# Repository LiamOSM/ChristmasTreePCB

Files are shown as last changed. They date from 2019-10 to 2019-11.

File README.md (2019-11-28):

# Christmas Tree PCB
**A PCB Christmas Tree Ornament that glows and plays music!**

This is a thing I designed for McMaster University's IEEE Student Branch. An ATtiny85 microcontroller runs the program I created, which displays several light patterns. Pressing the "Light" button cycles through these patterns. The "Music" button starts a simple version of Jingle Bells, which loops forever until either of the buttons is pressed.

After cycling through all the light modes by pressing the "Light" button, there is an "off" mode. In this mode, the microcontroller is in a deep sleep and the entire circuit draws only 0.2 microamperes. With a standard 200mAh coin cell, the circuit will last over a hundred years in this sleep mode!

The "Light" button actually does a hard-reset to the microcontroller, which is how it's able to exit the sleep mode. Therefore, to make the button able to cycle through modes, the current state is stored in EEPROM. When the microcontroller resets, the state is read from EEPROM, incremented by one, and stored back to EEPROM. If the current state is zero, the microcontroller enters the deep sleep mode. Otherwise, it enters the corresponding light pattern mode.

oops PCB Layout
oops PCB Layout

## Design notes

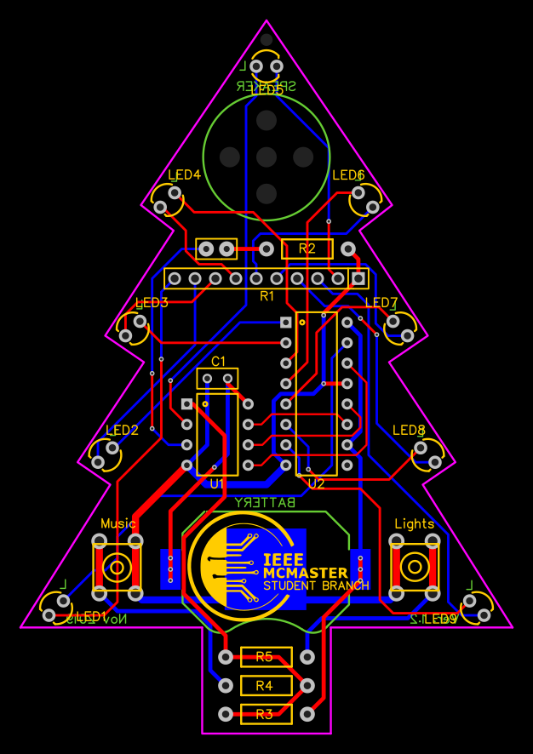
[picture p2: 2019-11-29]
PCB & Circuit Stuff/PCB Layout.png

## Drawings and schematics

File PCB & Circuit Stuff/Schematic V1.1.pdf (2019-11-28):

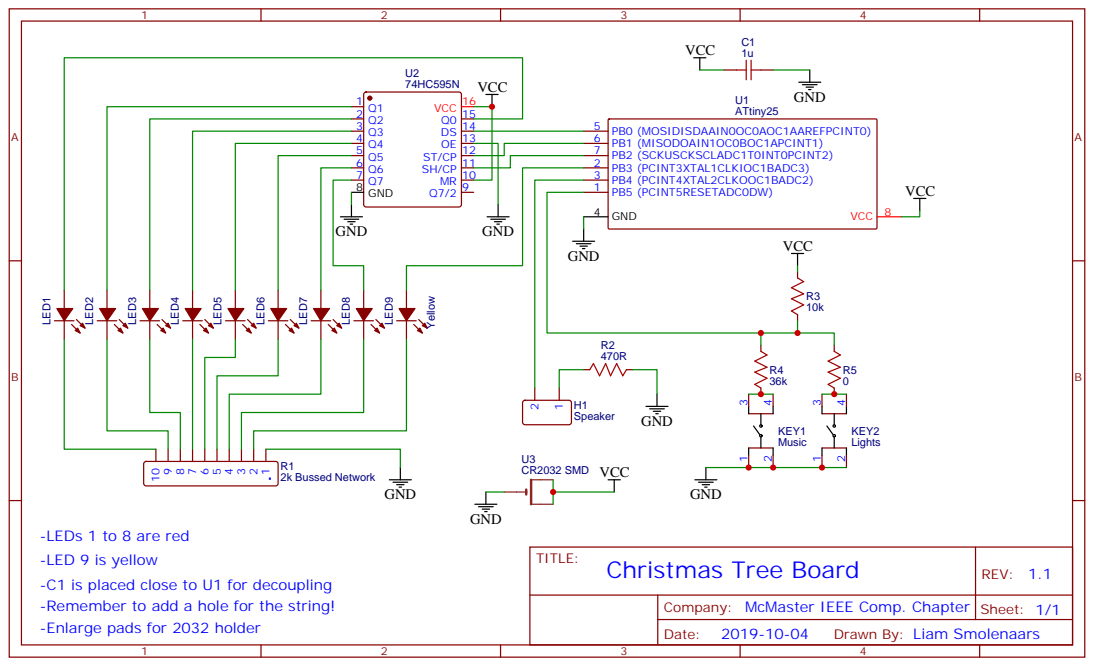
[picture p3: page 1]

MR 10 SH/CP 11 ST/CP 12 OE 13 DS 14 Q0 15 VCC 16

-LEDs 1 to 8 are red
-LED 9 is yellow
-C1 is placed close to U1 for decoupling
-Remember to add a hole for the string!
-Enlarge pads for 2032 holder

Company: McMaster IEEE Comp. Chapter

Drawn By: Liam Smolenaars

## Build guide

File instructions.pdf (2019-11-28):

### Parts List

Quantity | Label | Part Description | Image
1 | R1 | Resistor Network
1 | U1 | ATtiny85 Microcontroller
1 | U1 | 8 Pin Socket
8 | LED1-4, LED6-9 | Red LEDs
1 | LED5 | Yellow LED
1 | C1 | Ceramic Capacitor
2 | Music, Lights | Pushbuttons
1 | Speaker | Speaker
1 | U2 | Shift Register
1 | U2 | 16 Pin Socket
1 | Battery | Battery Holder
1 | Battery | Battery
1 | R3 | 10k Resistor (brown, black, orange)

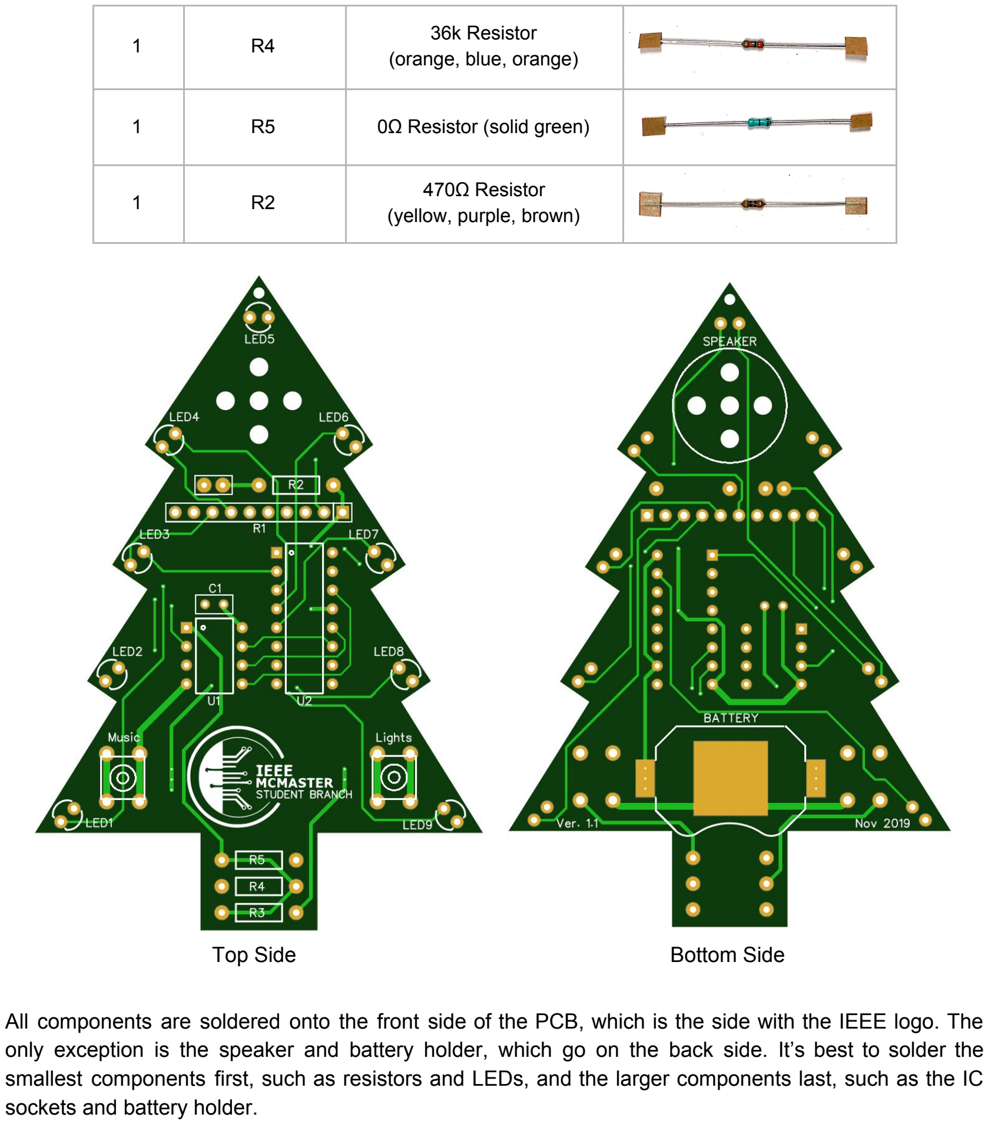
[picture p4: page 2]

1 | R4 | 36k Resistor (orange, blue, orange)
1 | R5 | 0Ω Resistor (solid green)
1 | R2 | 470Ω Resistor (yellow, purple, brown)
Top Side | Bottom Side

All components are soldered onto the front side of the PCB, which is the side with the IEEE logo. The only exception is the speaker and battery holder, which go on the back side. It’s best to solder the smallest components first, such as resistors and LEDs, and the larger components last, such as the IC sockets and battery holder.

### Step-By-Step Instructions

1. Insert and solder the following resistors: R2, 470Ω, yellow purple brown R3, 10kΩ, yellow orange black R4, 36kΩ, orange blue orange R5, 0Ω, solid green
2. Place the yellow LED at the top of the tree, in position “LED5”. Place the red LEDs in the remaining positions (LED1-4, LED6-9).
IMPORTANT: LEDs are polarized, meaning they must be placed in the correct orientation! Make sure the flat side of the LED is facing the bottom of the tree PCB.
3. Solder the pushbuttons in their positions, labelled “Music” and “Lights”.
4. Solder the ceramic capacitor in position C1.
5. Place the resistor network (the long brown component with 10 pins) in position R1.
IMPORTANT: The black dot on one end of this component must be on the right side of the PCB. This should match the square in the outline on the PCB.

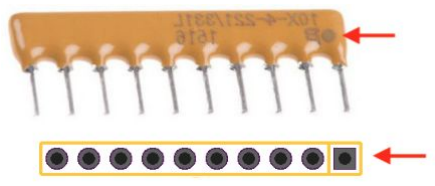
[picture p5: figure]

6. Place the 8-pin socket in position U1, and the 16-pin socket in position U2.
7. Flip the PCB over. Peel off the white paper from the speaker to reveal the adhesive, and stick in in place, centred over the 5 sound holes.
8. Insert the speaker wires through the two unlabelled holes just below the speaker, and solder them. The polarity doesn’t matter here.
9. Apply a small amount of solder (~1cm length of solder) to the square pad where the battery goes.

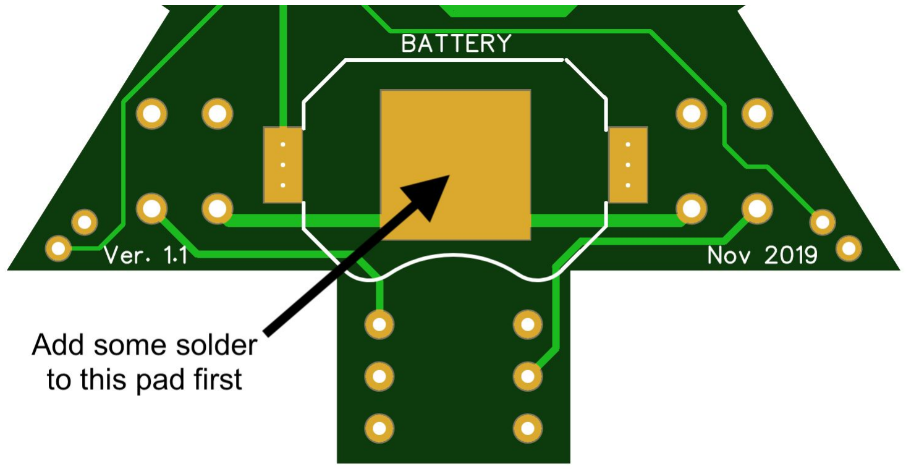
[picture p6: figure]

10. Place the battery holder and solder the two side terminals.
11. Insert the 8-pin chip into its socket, making sure the small dot on the chip faces up.
12. Insert the 16-pin chip into its socket, making sure the notch on the chip faces up.

## Before inserting the battery, please ask a volunteer to check your board to avoid any blown components!

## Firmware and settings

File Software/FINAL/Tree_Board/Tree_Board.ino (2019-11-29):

// In the previous revision, the code was written for a 75k resistor
// on the music button, but a 36k resistor was included in the kit.
// This revision includes a software patch so that the boards will
// work with either a 36k OR 75k resistor (or any value in between)

#include <avr/sleep.h>
#include <EEPROM.h>
#include "pitches.h"

const uint8_t spkrPin = 4; // Speaker
const uint8_t led5Pin = 3; // LED5 (top of tree)

// shift register pins
const uint8_t clockPin = 2; // SH_CP
const uint8_t latchPin = 1; // ST_CP
const uint8_t dataPin = 0; // DS

// both buttons are on A0
// note that the "lights" button resets the chip
const int btnPin = A0; // Buttons
const uint8_t lightsDebounce = 50;
const int musicDebounce = 200;
const int btnMusicThreshold = 850;
//const int btnLightThreshold = 798;
//const int btnBothThreshold  = 722;
const int tolerance = 100;

uint8_t sr = 0b00000000;
uint8_t mode = 0;

// Some light modes just need to be set once.
// This flag is used to check if that's happened.
uint8_t complete = 0;

bool music = 0;
uint8_t max_state = 7; // last LED mode, rollover to zero next

// modes:
// 0 = off
// 1 = full-blast
// 2 = flashing
// 3 = see-saw
// 4 = twinkle
// 5 = chase
// 6 = inverted chase
// 7 = superlike

int notes[] = {
  NOTE_E5, NOTE_E5, NOTE_E5,
  NOTE_E5, NOTE_E5, NOTE_E5,
  NOTE_E5, NOTE_G5, NOTE_C5, NOTE_D5,
  NOTE_E5,
  NOTE_F5, NOTE_F5, NOTE_F5, NOTE_F5,
  NOTE_F5, NOTE_E5, NOTE_E5, NOTE_E5, NOTE_E5,
  NOTE_E5, NOTE_D5, NOTE_D5, NOTE_E5,
  NOTE_D5, NOTE_G5
};

uint8_t toneLengths[] = {
  8, 8, 4,
  8, 8, 4,
  8, 8, 8, 8,
  2,
  8, 8, 8, 8,
  8, 8, 8, 16, 16,
  8, 8, 8, 8,
  4, 4
};

void setup() {
  pinMode(latchPin, OUTPUT);
  pinMode(clockPin, OUTPUT);
  pinMode(dataPin, OUTPUT);
  pinMode(led5Pin, OUTPUT);
  pinMode(spkrPin, OUTPUT);

  // clear LEDs ASAP (SR sets them high on reset)
  clrLED();

  // on startup, get new state from EEPROM
  mode = EEPROM.read(0);
  if (mode > max_state)
    mode = 0;
  delay(lightsDebounce);
  // write next state into EEPROM
  EEPROM.write(0, mode + 1);
}

void loop() {
  // counters and states for light modes
  static bool mode2state = 0;
  static uint8_t mode3counter = 1;
  static bool mode4state = 0;
  static uint8_t mode56counterA = 1;
  static uint8_t mode56counterB = 2;
  static uint8_t mode7counter = 1;

  // counters and timers for music
  static unsigned long lastTime = 0;
  static unsigned long musicTimer = 0;
  static int noteCounter = -1; // idk, it just works this way

  if (music) {
    int noteDuration = 2000 / toneLengths[noteCounter];
    if (abs(millis() - musicTimer) >= (noteDuration * 1.30)) {
      musicTimer = millis();
      noteCounter = (noteCounter >= (sizeof(notes) / sizeof(int))) ? 0 : noteCounter + 1;
      tone(spkrPin, notes[noteCounter], noteDuration);
    }

    if (abs(millis() - musicTimer) >= noteDuration) {
      noTone();
    }
  }


  if (!complete) { // lights need updating
    switch (mode) {
      case 0: // idle, 0.2uA current draw
        clrLED();
        complete = 1;
        low_power();
        // once low_power() is called, the microcontroller
        // is basically "bricked" until reset is pressed
        break;
      case 1: // full-blast
        fullLED();
        complete = 1;
        break;
      case 2: // flashing
        if (abs(millis() - lastTime) > 500) { // 0.5 sec passed
          lastTime = millis();
          mode2state = !mode2state; // toggle
          if (mode2state)
            fullLED();
          else
            clrLED();
        }
        break;
      case 3: // see-saw
        if (abs(millis() - lastTime) > 80) { // 100ms passed
          lastTime = millis();
          if (mode3counter >= 1 && mode3counter <= 9)
            setLED(mode3counter, 1);
          else if (mode3counter >= 10 && mode3counter <= 18)
            setLED(mode3counter - 9, 0);
          else if (mode3counter >= 19 && mode3counter <= 27)
            setLED(9 - (mode3counter - 19), 1);
          else if (mode3counter >= 28 && mode3counter <= 36)
            setLED(9 - (mode3counter - 28), 0);
          mode3counter = (mode3counter >= 36) ? 1 : mode3counter + 1;
        }
        break;
      case 4: // twinkle
        if (abs(millis() - lastTime) > 100) { // 100ms passed
          lastTime = millis();
          mode4state = !mode4state;
          for (uint8_t i = 1; i <= 9; i ++) {
            setLED(i, (i % 2) ^ mode4state );
          }
        }
        break;
      case 5: // chase
        if (abs(millis() - lastTime) > 80) { // 50ms passed
          lastTime = millis();
          setLED(mode56counterA, 0);
          mode56counterA = (mode56counterA >= 11) ? 1 : mode56counterA + 1;
          mode56counterB = (mode56counterB >= 11) ? 1 : mode56counterB + 1;
          setLED(mode56counterB, 1);
        }
        break;
      case 6: // inverted chase
        if (abs(millis() - lastTime) > 80) { // 50ms passed
          lastTime = millis();
          setLED(mode56counterA, 1);
          mode56counterA = (mode56counterA >= 11) ? 1 : mode56counterA + 1;
          mode56counterB = (mode56counterB >= 11) ? 1 : mode56counterB + 1;
          setLED(mode56counterB, 0);
        }
        break;
      case 7: // superlike
        if (abs(millis() - lastTime) > 100) { // 50ms passed
          lastTime = millis();
          setLED(mode7counter, 0);
          setLED(10 - mode7counter, 0);
          mode7counter = (mode7counter >= 5) ? 1 : mode7counter + 1;
          setLED(mode7counter, 1);
          setLED(10 - mode7counter, 1);
        }
        break;
    }
  }

  // check if music button pressed
  int reading = analogRead(A0);
  if ((abs(reading - btnMusicThreshold) < tolerance)) {
    noteCounter = -1; // reset song, so it doesn't resume from the middle
    music = !music;
    if (music) {
      EEPROM.write(0, mode); // if button is used to turn off music, don't increment mode
    }
    else {
      EEPROM.write(0, mode + 1);
      noTone();
    }
    delay(musicDebounce);
  }
}


void setLED(int index, bool state) {
  // the states are all inverted because I'm too lazy to invert
  // each ternary statement, and I accidentalyl made them all
  // backwards originally
  switch (index) {
    case 1:
      sr = (!state) ? (sr & 0b11111110) : (sr | 0b00000001);
      break;
    case 2:
      sr = (!state) ? (sr & 0b11111101) : (sr | 0b00000010);
      break;
    case 3:
      sr = (!state) ? (sr & 0b11111011) : (sr | 0b00000100);
      break;
    case 4:
      sr = (!state) ? (sr & 0b11110111) : (sr | 0b00001000);
      break;
    case 5:
      digitalWrite(led5Pin, state ? HIGH : LOW);
      break;
    case 6:
      sr = (!state) ? (sr & 0b11101111) : (sr | 0b00010000);
      break;
    case 7:
      sr = (!state) ? (sr & 0b11011111) : (sr | 0b00100000);
      break;
    case 8:
      sr = (!state) ? (sr & 0b10111111) : (sr | 0b01000000);
      break;
    case 9:
      sr = (!state) ? (sr & 0b01111111) : (sr | 0b10000000);
      break;
    default:
      break;
  }
  if (index != 5) {
    digitalWrite(latchPin, LOW);
    shiftOut(dataPin, clockPin, MSBFIRST, sr);
    digitalWrite(latchPin, HIGH);
  }
}

void clrLED() {
  sr = 0b00000000;
  digitalWrite(latchPin, LOW);
  shiftOut(dataPin, clockPin, MSBFIRST, sr);
  digitalWrite(latchPin, HIGH);
  digitalWrite(led5Pin, LOW);
}

void fullLED() {
  sr = 0b11111111;
  digitalWrite(latchPin, LOW);
  shiftOut(dataPin, clockPin, MSBFIRST, sr);
  digitalWrite(latchPin, HIGH);
  digitalWrite(led5Pin, HIGH);
}

void low_power() {
  // the chosen sleep mode (SLEEP_MODE_PWR_DOWN)
  // disables pretty much everything except the
  // watchdog timer and interrupts, neither of
  // which are being used in this program
  set_sleep_mode(SLEEP_MODE_PWR_DOWN);
  ADCSRA &= ~(1 << ADEN); // disable ADC
  sleep_enable(); // set Sleep Mode Control Register enable bit to 1
  sleep_cpu(); // enter sleep mode now
}

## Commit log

2019-10-18 Added schematic and PCB renderings
2019-10-18 Added Gerber files and Altium files
    [Schematic.schdoc]
2019-11-19 Update framework.ino
    Made the framework a little bit more generalized
2019-11-20 Create framework_low_power.ino
    it's like framework.ino, but with a low-power sleep mode
2019-11-20 Update framework_low_power.ino
    removed garbage
2019-11-23 Final release added
    Final code revision is now available under Software > FINAL > Tree Board
2019-11-28 Updated all files to V1.1
    [PCB.pcbdoc, Sheet_1.schdoc]
2019-11-29 Updated PCB files
    Added an 'L' on bottom silkscreen, indicating where the long-lead of each LED should go. This should make it harder to accidentally put the LEDs in backwards.
    [PCB.pcbdoc]
